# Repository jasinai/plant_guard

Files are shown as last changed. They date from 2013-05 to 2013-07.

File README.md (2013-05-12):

Plant Guard
===========

This project helps you monitoring, watering and keeping care of your (indoor) plants.

What you need
-------------

  * An Arduino Uno or similar microcontroller Board (code is written in Arduino IDE, but we plan to port it to C)
  * A WiFly shield for the arduino
  * A twitter account and a wifi in range of you plant
  * An LM35 temperature sensor
  * An LM358 Op-Amp
  * 1x 220 Ohm resistor
  * 1x 10k Ohm resistor
  * 3x 100k Ohm resistors
  * A humidity sensor, built from two plug connector pins soldered to wire (spacing is important: use standard plug connector pins for this!)
  * A 12V elecronically open- and closeable valve
  * A plastic bottle with bottom cut off and some stand to safely put it upside down
  * some water tube to connect bottle, valve and plant
  * a willing (and maybe robust) plant :)

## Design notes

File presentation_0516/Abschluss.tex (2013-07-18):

\documentclass[bigger]{beamer}
\usepackage[utf8]{inputenc}
\usepackage[T1]{fontenc}
\usepackage{color}
\usepackage{graphicx}
\usepackage{eurosym}
\usepackage{parcolumns}

\DeclareGraphicsExtensions{.png,.pdf,.jpg}
\graphicspath{{./pics/}}

%Global Background must be put in preamble
\usebackgroundtemplate%
{%
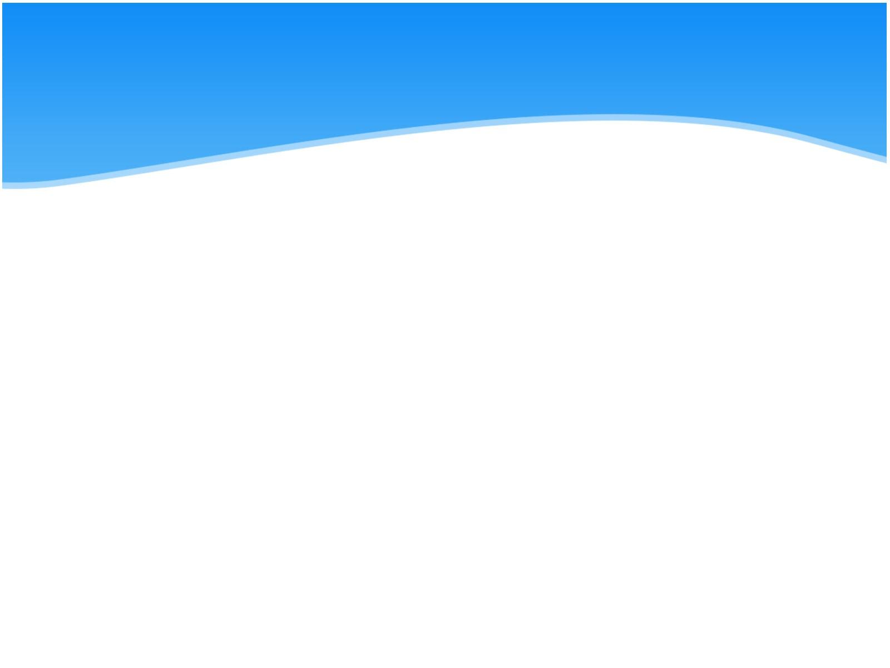
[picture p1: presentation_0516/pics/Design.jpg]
    %
}

\newcommand{\topic}[1]{{\huge{\textcolor{white}{\textbf{#1}}}}}
%\newcommand{\topic}[1]{\textbf{#1}}

\begin{document}
{
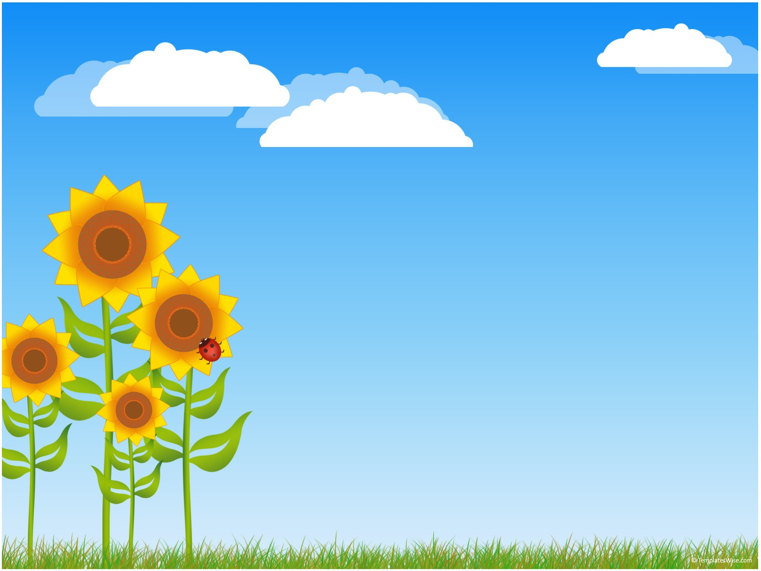
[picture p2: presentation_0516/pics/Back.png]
\usebackgroundtemplate{}%
\begin{frame}
%Title: leer, vielleicht noch unsere Namen einfügen
	\begin{figure}[H]
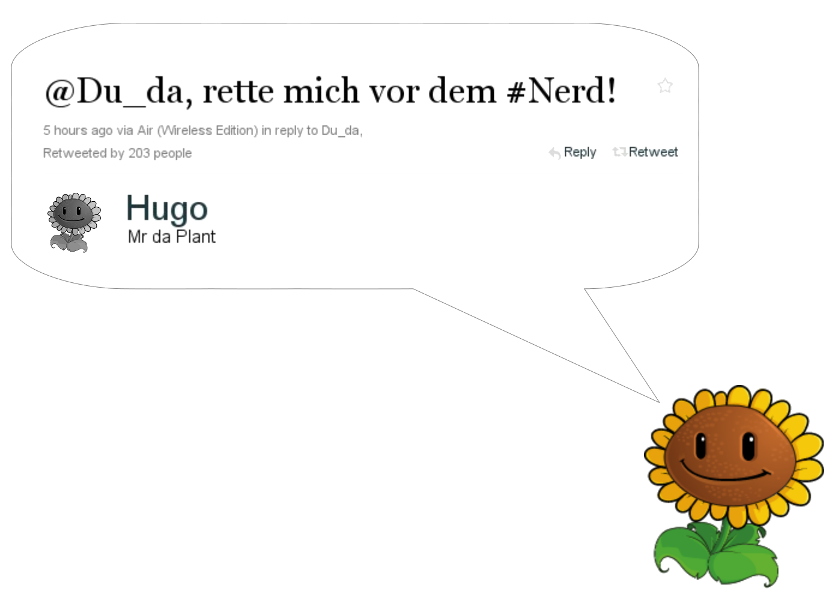
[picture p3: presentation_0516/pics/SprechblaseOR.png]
		
	\end{figure}

\end{frame}
}

\begin{frame}{\topic{Plant Guard}}
   \begin{itemize}
      \item Twitter für Kommunikation
      \item Messungen: Feuchtigkeit*, Temperatur, Wasserstand, uvm.
      \item kann Pflanzen gießen
      \item Erweiterbarkeit gegeben*
      \item Kosten sind relativ gering*
   \end{itemize}
*dazu später mehr Informationen
\end{frame}

\begin{frame}{\topic{Vergleich (andere Projekte)}}
	\begin{itemize}
		\item twittern oder nutzen spezielle Netzwerkprogramme
		\item meist keine Bewässerung (nur bei Hobbyprojekten)
		\item weniger Sensoren (meist nur Feuchtigkeit)
		\item dafür ein Projekt mit Pflanzen-DB für Konfiguration
		\item ein Bausatz/Gerät meist um {100\euro} oder nicht erhältlich
	\end{itemize}
\end{frame}

\begin{frame}{\topic{Vorteile des Plant Guard}}
	\begin{itemize}
		\item Pflanzeninfos über Twitter weltweit verfügbar
		%\item Multiuser (z.B. für die Gießvertretung)
		\item automatische Bewässerung
		\item erweiterbar (mehr Sensoren, mehr Pflanzen, ...)
		\item bei Stromausfall wird inzwischen später gegossen
	\end{itemize}
\end{frame}

\begin{frame}{\topic{Probleme}}
	\begin{itemize}
		\item Inkontinenz beim Start
		\item wenn der PlantGuard zuviel gießt, könnte der Topf überlaufen
		\item ziemlich großer Behälter, schlecht zu verstecken, leicht zu kippen, muss höher stehen als die Pflanze
		\item Abdichtung des Wasserbehälters
		\item viele und lange Kabel
		\item hohe Kosten bei verteilt stehenden Pflanzen (pro Pflanze ein PlantGuard)
	\end{itemize}
\end{frame}

\begin{frame}{\topic{Kosten}}
	\begin{itemize}
		\item Arduino+WiFly: ab 60\euro
		\item Ventil: 7,50\euro
		\item Sensoren: je nach Anzahl/Art
		\item Platine und Material: wenige \euro
	\end{itemize}
	Summe: ca. 75\euro
\end{frame}

\begin{frame}{\topic{Sensoren}}
	\begin{itemize}
		\item Temperatur
		\item Feuchtigkeit
		\item Wasserstand
	\end{itemize}
weitere Ideen folgen
\end{frame}

\begin{frame}{\topic{Temperatur}}
	\begin{itemize}
		\item benötigt einen OpAmp
		\item lange Drähte für freie Positionierung
		\item misst im Bereich der Raumtemperatur
		\item direkt auf der Platine
	\end{itemize}
\end{frame}

\begin{frame}{\topic{Temperatursensor}}
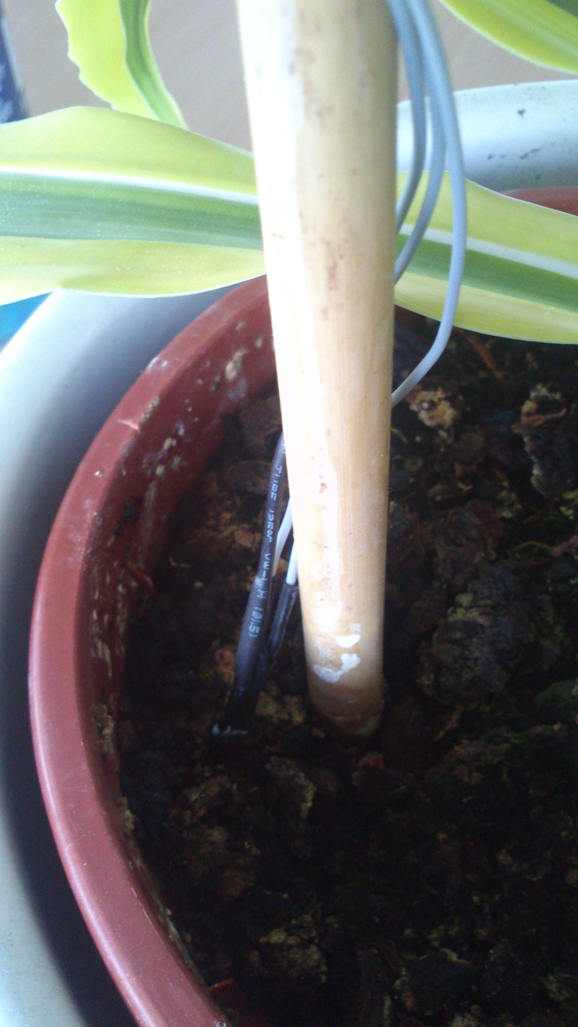
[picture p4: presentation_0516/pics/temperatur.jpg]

\end{frame}

\begin{frame}{\topic{Feuchtigkeit}}
	\begin{itemize}
		\item zwei lange Metallstäbe, die mit festem Abstand zueinander in den Boden gesteckt werden
		\item Spannungsmessung mit der Erde als Widerstand. Je niedriger der Wert, desto feuchter die Erde
		\item Nutzung von Wechselspannung (durch Umpolen von 2 Pins) schont die Pflanze
	\end{itemize}
\end{frame}

\begin{frame}{\topic{Feuchtigkeitssensor}}
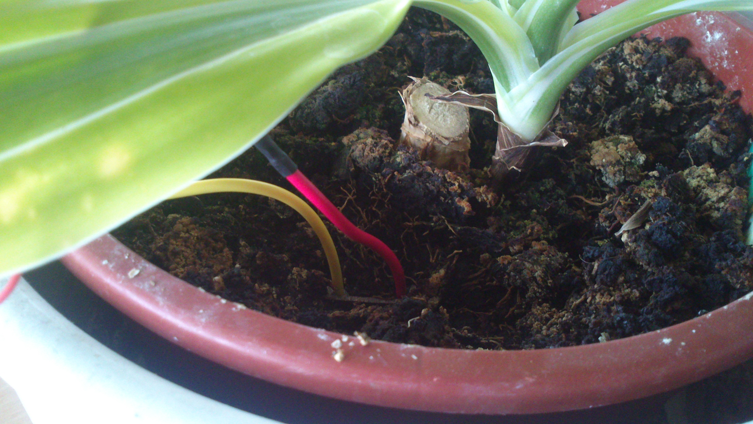
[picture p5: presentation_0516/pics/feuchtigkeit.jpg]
\begin{center}\end{center}
\end{frame}

\begin{frame}{\topic{Wasserstand}}
	\begin{itemize}
		\item zwei sehr lange Drähte mit festem Abstand
		\item am Arduino werden 4,5 bis 4,9 Volt gemessen
		\item ca. 82stufige Messungen
		\item bedingt wichtig für Nachrichten
		\item sehr wichtig für Pumpen (nur im Wasser betreiben!)
	\end{itemize}
\end{frame}

\begin{frame}{\topic{Wasserstandssensor}}
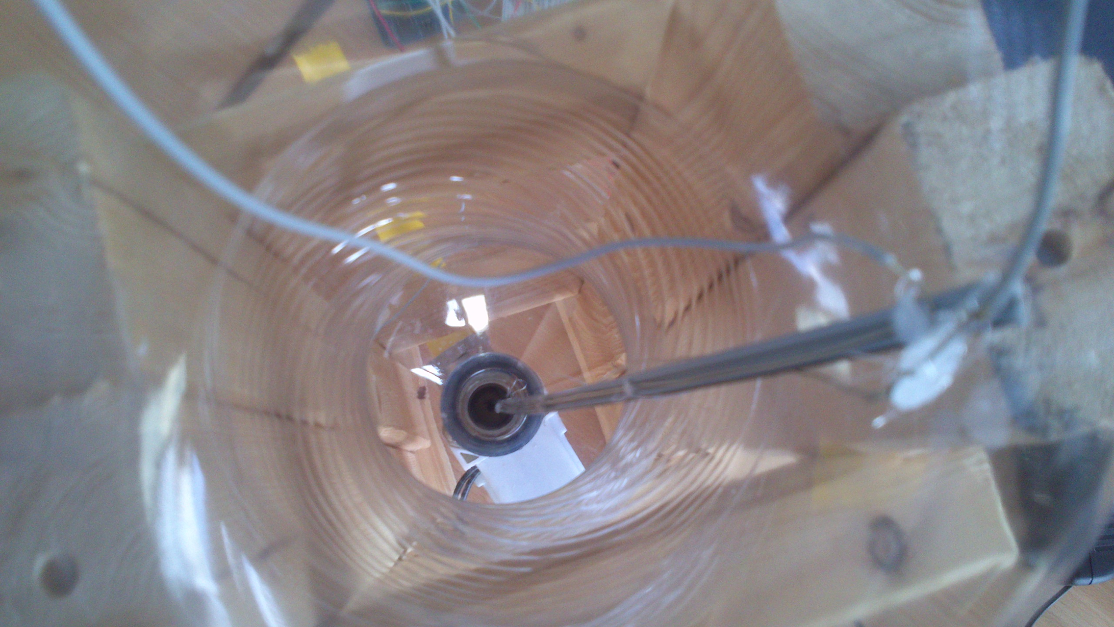
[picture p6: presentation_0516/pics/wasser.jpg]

\end{frame}

\begin{frame}{\topic{Aktuatoren/Ventil}}
	\begin{itemize}
		\item leise
		\item nutzt Schwerkraft
		\item z.Z. auf Flaschen-Tank begrenzt, generell ist der Tank ersetzbar
		\item man muss das Ventil richtig ausrichten (um nicht den Bereich um die Pflanze zu gießen)
	\end{itemize}
\end{frame}

\begin{frame}
%Bild von aktueller Platine
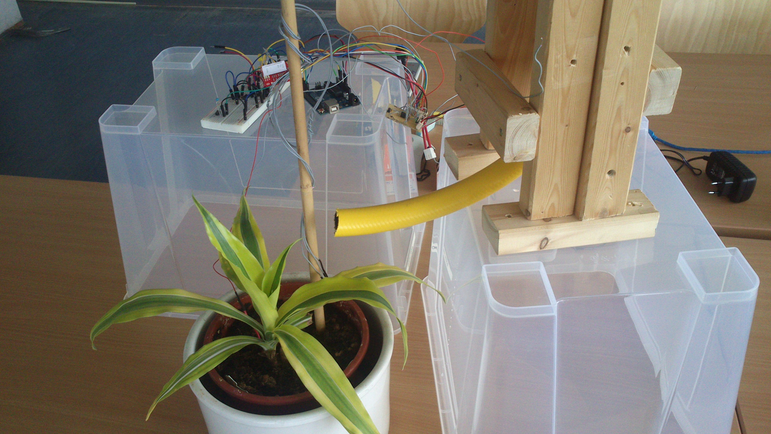
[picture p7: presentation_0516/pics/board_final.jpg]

\end{frame}

\begin{frame}
%Bild von aktueller Platine
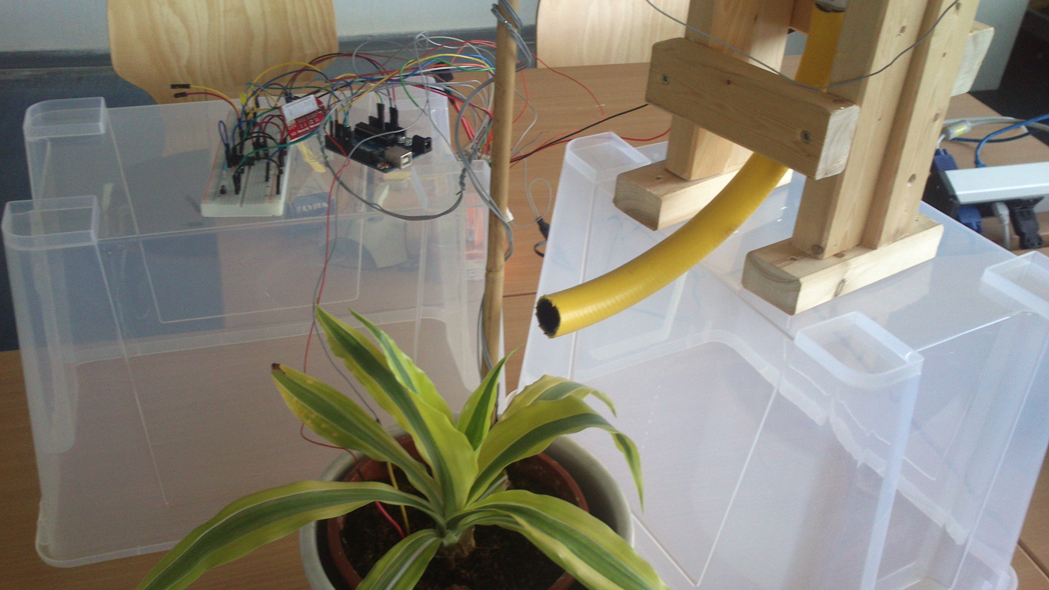
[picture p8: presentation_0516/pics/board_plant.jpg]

\end{frame}

\begin{frame}
%Bild von aktueller Platine
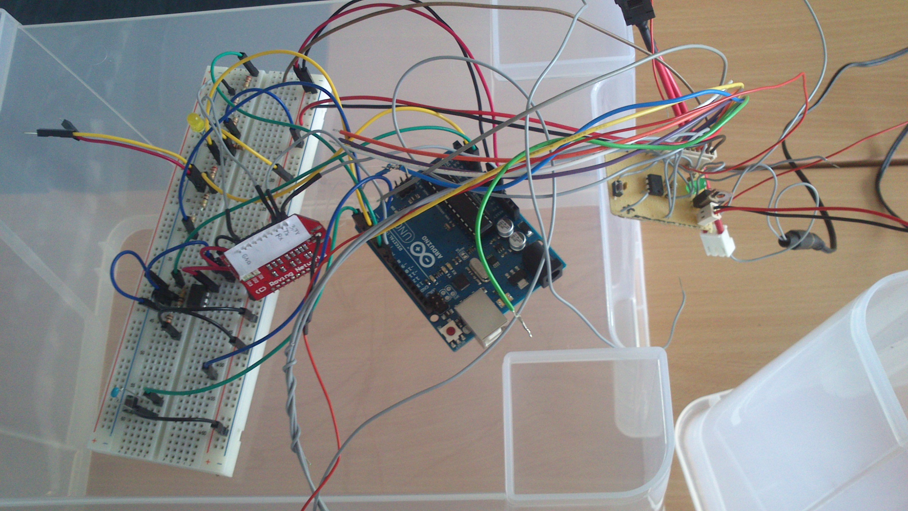
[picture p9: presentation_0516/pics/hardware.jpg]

\end{frame}

\begin{frame}{\topic{Bewässerung}}
% %früher / heute vergleich
%     \begin{columns}
%       \column[c]{.50\linewidth}
%         \begin{enumerate}
% 			\item verbreiterte Stellfläche
% 			\item Messkabel
% 			\item Ventilansteuerung
% 			\item Verbindung Vorrat $\rightarrow$ Ventil
%         \end{enumerate}
%       \column[c]{.50\linewidth}
%         \includegraphics[width=150px]{System.jpg}
%     \end{columns}
\url{http://www.youtube.com/watch?feature=player_embedded&v=Uci__lRXZsU}
\end{frame} 

\begin{frame}{\topic{Softwareübersicht}}
	\begin{itemize}
		\item 20kb groß (viel für Twitter)
		\item Regelschleife (wenn zu trocken, gieße)
		\item Zeitsteuerung mit "Gieße alle X Minuten" möglich
      \item Wichtige Parameter (z.B. Temperatur- und Feuchteschwellwerte) sind in eine Konfigurationsdatei ausgelagert
		\item liegt unter \url{http://github.com/jasinai/plant\_guard}
	\end{itemize}
\end{frame}

% \begin{frame}{\topic{Bewässerung}}
% %früher / heute vergleich
%        \includegraphics[width=350px]{Anschluss.jpg}
% \end{frame}

\begin{frame}{\topic{Tweets}}
	\begin{itemize}
      \item "Mir ist kalt! Stell mich an einen wärmeren Ort. Aktuelle Temperatur: X"
      \item "Puh, ist das warm! Ein bisschen Schatten wäre nicht schlecht. Aktuelle Temperatur: 33"
      \item "Mir ist warm. Es ist sind 30 C. Stell mich woanders hin."
      \item "Mensch, gib mir Wasser!"
	\end{itemize}
\end{frame}

\begin{frame}{\topic{mögliche Upgrades}}
	\begin{itemize}
		\item Pumpe statt Ventil (+{5\euro}, mehr Strom nötig, etwas lauter)
		\item mehr Pflanzen pro PlantGuard überwachen
		\item mehr Sensoren
		\item weg vom Arduino/WiFly
		\item Datenbank für Gießparameter
		\item diverse Hardwareverbesserungen
	\end{itemize}
\end{frame}

\begin{frame}{\topic{Pumpe statt Ventil}}
	\begin{itemize}
		\item Ventilansteuerung kompatibel mit einigen Pumpen
		\item Zeiten müssten angepasst werden
		\item Füllstand wäre noch wichtiger
		\item Behälter wäre beliebig, leichter zu verstecken
		\item kein Leck abzudichten, dafür eventuell mehr Schlauch zu verlegen
	\end{itemize}
\end{frame}

\begin{frame}{\topic{mehrere Pflanzen pro PlantGuard}}
	\begin{itemize}
		\item drückt die Kosten
		\item spart Strom (gegenüber einem Arduino pro Pflanze)
		\item mehr Anschlüsse nötig
    	\item Pflanzen sollten dicht beieinander stehen und möglichst selten bewegt werden
		\item DeMux: lange Kabel
		\item Funkchip: Protokoll ausarbeiten
	\end{itemize}
\end{frame}

\begin{frame}{\topic{weitere/andere Sensoren}}
	\begin{itemize}
		\item mehrere Feuchtigkeitssensoren
		\item längere Feuchtigkeitssensoren
		\item andere Füllstandssensorik
		\item mehrere Temperatursensoren
      	\item +Helligkeitssensor
		\item +Farbsensor, Kunstlicht/Sonne
		\item +Barometer
		\item +Kippsensor (für Notfälle)
	\end{itemize}
\end{frame}

% \begin{frame}{\topic{drahtlose Verbindung}}
% 	\begin{itemize}
% 		\item man spart sich eine (De)Mux-Platine für mehrere Messstationen
% 		\item man kann durch Anpassungen am Protokoll mehr Pflanzen versorgen
% 		\item muss gesichert werden (Übertragungsfehler, ...)
% 		\item keine Kabel quer durch den Raum/die Etage nötig
% 	\end{itemize}
% \end{frame}

% \begin{frame}{\topic{ohne Arduino}}
% 	\begin{itemize}
% 		\item NetIO mit Ethersex + SD-Karte = Webserver
% 		\item geringere Kosten, ca. 25\euro
% 		\item lange erprobt, sehr ausfallfrei
% 		\item sicher, da kein WLan benötigt wird
% 		\item kompatibel mit einem Sender-Chip
% 	\end{itemize}
% \end{frame}

\begin{frame}{\topic{Hardwareverbesserungen}}
	\begin{itemize}
		\item Hülle/Gehäuse
		\item professionelle Platine, eigenes Layout
		%\item Vorgeben zweier (De)mux-Schaltung (Norm für die Software)
	\end{itemize}
\end{frame}

\begin{frame}{\topic{Datenbank mit Pflanzendaten}}
	\begin{itemize}
		\item man müsste den PlantGuard nicht anlernen
		\item dafür aber eine Datenbank mit Informationen füllen und pflegen
		\item Datenbank liefert eine passende config.h
		\item Upload über die Arduino-IDE bzw. avrdude
		\item Nachteil: User könnte die falsche Pflanze wählen oder in der Größe irren
	\end{itemize}
\end{frame}

\usebackgroundtemplate{}%
\begin{frame}{}
	\begin{figure}[H]
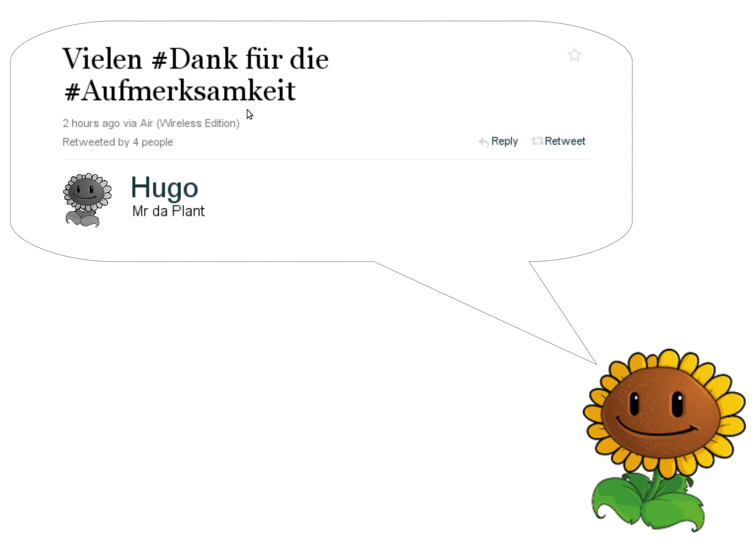
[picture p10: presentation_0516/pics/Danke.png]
		
	\end{figure}
\end{frame}

\end{document}

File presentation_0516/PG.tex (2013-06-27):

\documentclass[bigger]{beamer}
\usepackage[utf8]{inputenc}
\usepackage[T1]{fontenc}
\usepackage{color}
\usepackage{graphicx}
\usepackage{eurosym}
\usepackage{parcolumns}

\DeclareGraphicsExtensions{.png,.pdf,.jpg}
\graphicspath{{./pics/}}

%Global Background must be put in preamble
\usebackgroundtemplate%
{%
    %
}

\newcommand{\topic}[1]{{\huge{\textcolor{white}{\textbf{#1}}}}}
%\newcommand{\topic}[1]{\textbf{#1}}

\begin{document}
{
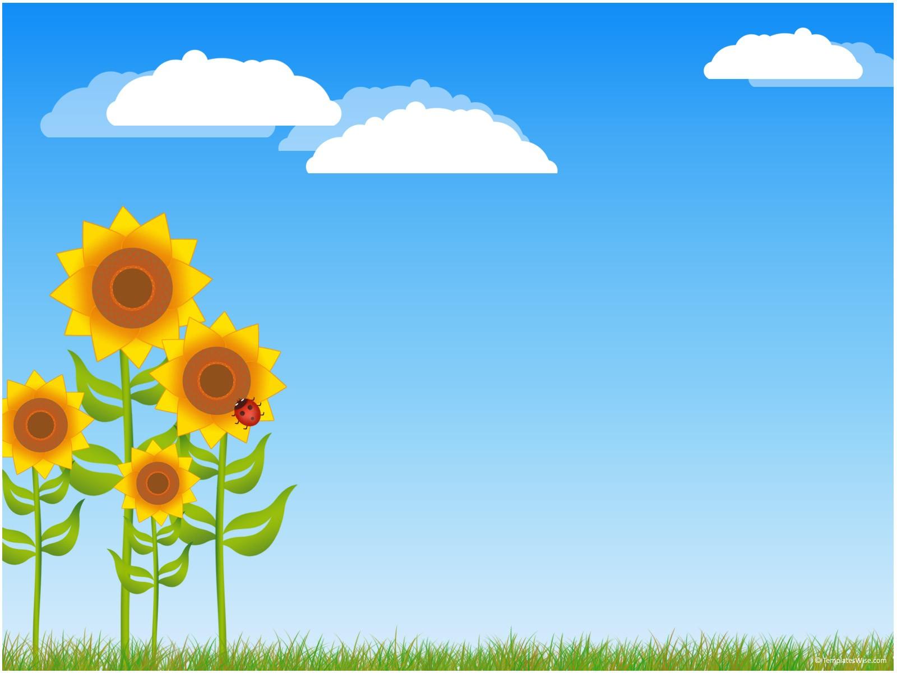
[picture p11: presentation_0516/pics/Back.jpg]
\usebackgroundtemplate{}%
\begin{frame}
%Title: leer, vielleicht noch unsere Namen einfügen
\begin{figure}[H]

\end{figure}

\end{frame}
}

\begin{frame}{\topic{Übersicht}}
   \begin{itemize}
      \item Auswahl existierender ähnlicher Projekte
      \item Vorstellung Plant Guard
      \item Zielgruppe
      \item Arbeitsstand
      \item Weitere Schritte
   \end{itemize}
\end{frame}

\begin{frame}{\topic{E-Plant}}
	\begin{itemize}
      \item Kommerzielles Projekt, Zielt auf Landwirtschaft
		\item Wird an die Pflanze angeklemmt
		\item Misst ähnlich wie ein EKG
		\item Umwelteinflüsse erkennen
		\item Wird noch nicht produziert
		\item \url{http://www.land-der-ideen.de/365-orte/preistraeger/e-plant-pflanzen-monitoring-sensor}
	\end{itemize}
\end{frame}

\begin{frame}{\topic{Botanicalls}}
	\begin{itemize}
      \item künstlerisch-wissenschaftlicher Hintergrund
		\item Twittert und/oder ruft an
		\item Nur Feuchtigkeit
		\item Bausatz kostet 100\$
		\item \url{http://www.botanicalls.com/}
	\end{itemize}
\end{frame}

\begin{frame}{\topic{Tomato Irrigation Project}}
	\begin{itemize}
      \item Hobby-Projekt
		\item Twittert
		\item Feuchtigkeitssensor
		\item automatische Bewässerung mit Pumpe
		\item nicht mehr aktiv
		\item \url{http://picasaweb.google.com/joouni/WateringSystem}
		\item \url{https://twitter.com/tomaatit}
	\end{itemize}
\end{frame}

\begin{frame}{\topic{Giess-o-mat}}
	\begin{columns}[T]
		\begin{column}{.5\textwidth}
			\begin{itemize}
            \item Hobby-Projekt
				\item automatisiertes Gießen
				\item Verwaltung der Pflanzen über Terminal
				\item Feuchtigkeitssensor
				\item \url{http://www.mikrocontroller.net/articles/Giess-o-mat}
			\end{itemize}
		\end{column}
		\begin{column}{.5\textwidth}
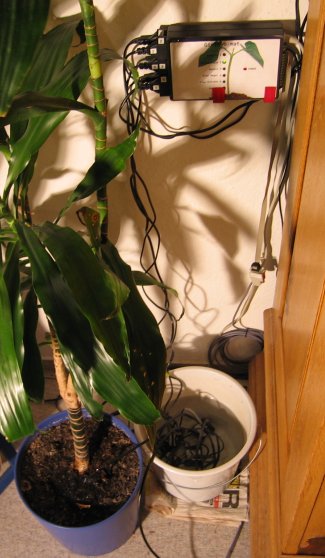
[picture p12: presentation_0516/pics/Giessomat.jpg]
			
		\end{column}
	\end{columns}
\end{frame}

\begin{frame}{\topic{GardenBot}}
	\begin{itemize}
      \item Hobby-Projekt
		\item Temperatur- und Feuchtigkeitsmessung
		\item automatisiertes Gießen
		\item Auch für den Garten gedacht
		\item (erstmal) nicht mehr aktiv
		\item \url{http://gardenbot.org/}
	\end{itemize}
\end{frame}

\begin{frame}{\topic{Koubachi}}
	\begin{itemize}
      \item kommerzielles Projekt eines schweizer Start-Ups
		\item Temperatur-, Feuchtigkeits- und Lichtsensor (nur mit Gerät)
		\item Wasser-, Düng-, Besprühplan auch ohne Gerät
		\item Gerät auch für mehrere Pflanzen, indoor und outdoor
		\item Config für Pflanzentypen im Internet
		\item Nur mit Iphone App oder Facebook-Account
		\item 90-200 Euro
		\item \url{http://www.koubachi.com/}
	\end{itemize}
\end{frame}

\begin{frame}{\topic{Parrot Flower Power}}
	\begin{itemize}
      \item kommerzielles Projekt
		\item Temperatur-, Feuchtigkeits- und Lichtsensor
		\item Düngerstandmessung
		\item Bluetooth + Smartphone
		\item Kommt irgendwann 2013 raus
		\item\url{http://www.parrot.com/flower-power/}
	\end{itemize}
\end{frame}

\begin{frame}{\topic{Patente}}
   Weiterhin existieren diverse Patente in dem Bereich, u.a. für
	\begin{itemize}
		\item selbstbewässernde Blumentöpfe
		\item Bewässerungssysteme für Bäume
      \item komplexere Systeme für die Landwirtschaft
      \item siehe auch \url{http://scholar.google.de/scholar?as_vis=1&q=plant+irrigation}
	\end{itemize}
\end{frame}

\begin{frame}{\topic{The "planned" guard}}
	\begin{itemize}
		\item Feuchtigkeitssensor
		\item Temperatursensor
		\item automatische Bewässerung
		\item Füllstandssensor
		\item Lichtsensor?
		\item einfache Möglichkeit zur Konfiguration
		\item ... und natürlich Tweets!
	\end{itemize}
\end{frame}

\begin{frame}{\topic{Abnehmer/Interessierte}}
	\begin{itemize}
		\item Neulinge, damit ihre erste Zimmerpflanze nicht ihre letzte wird
		\item Personen, die oft unterwegs sind und nicht jeden Tag zum gießen nach Hause kommen (können)
		\item Leute mit dem “braunen Daumen”, die trotzdem auf ein bisschen Grün nicht verzichten wollen
		\item Statistikhungrige (Wasserverbrauch, Lebenszeit, ...)
		\item Allen, die es einfach cool finden, wenn ihre Pflanze sich selber gießt
	\end{itemize}
\end{frame}

\begin{frame}{\topic{Bisherige Arbeiten}}
	\begin{itemize}
		\item Feuchtigkeitssensor für den Boden
		\item Temperatursensor
		\item Bewässerungsautomatisierung
		\item Grundgerüst der Software (https://github.com/jasinai/plant\_guard)
	\end{itemize}
\end{frame}
\begin{frame}
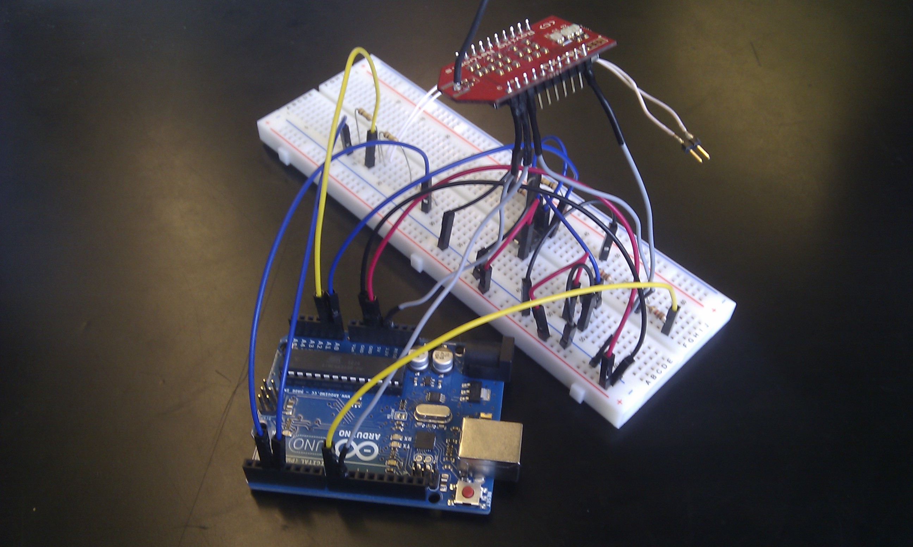
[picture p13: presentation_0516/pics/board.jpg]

\end{frame}
\begin{frame}{\topic{Temperatursensor}}
	\begin{itemize}
		\item LM35 aus dem Starterkit
	\end{itemize}
\end{frame}

\begin{frame}{\topic{Feuchtigkeitssensor}}
		\begin{itemize}
			\item Stiftleisten oder Nägel in Gips
			\item Korrisionsschutz: Wechselstrom
		\end{itemize}
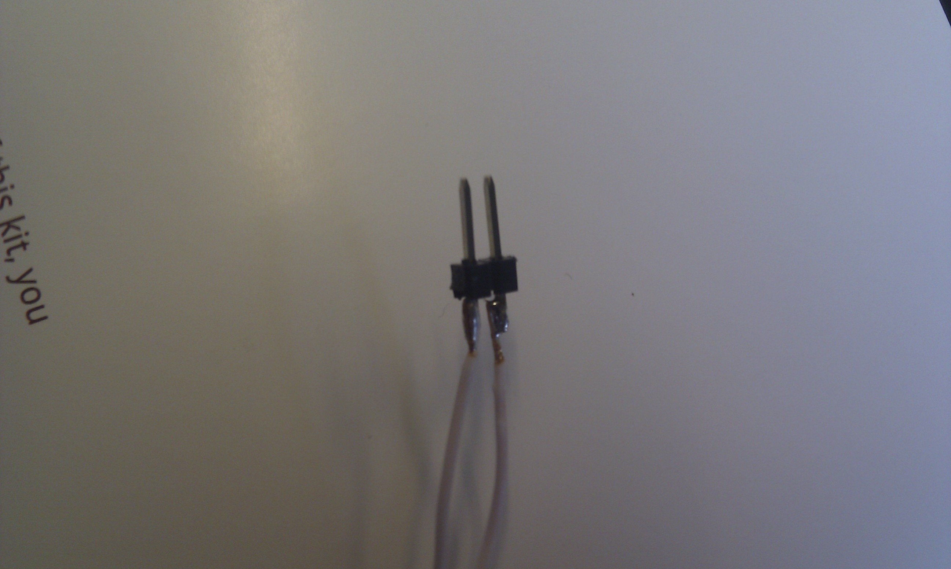
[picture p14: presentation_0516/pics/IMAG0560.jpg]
		
\end{frame}

\begin{frame}{\topic{Bewässerung}}
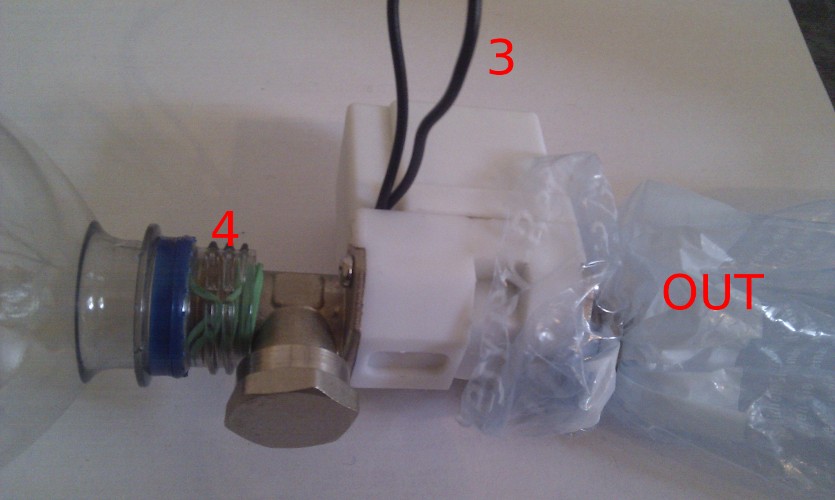
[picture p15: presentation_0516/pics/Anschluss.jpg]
       
\end{frame}

\begin{frame}{\topic{Bewässerung}}
    \begin{columns}
      \column[c]{.50\textwidth}
        \begin{enumerate}
			\item verbreiterte Stellfläche
			\item Messkabel
			\item Ventilansteuerung
			\item Verbindung Vorrat $\rightarrow$ Ventil
        \end{enumerate}
      \column[c]{.50\textwidth}
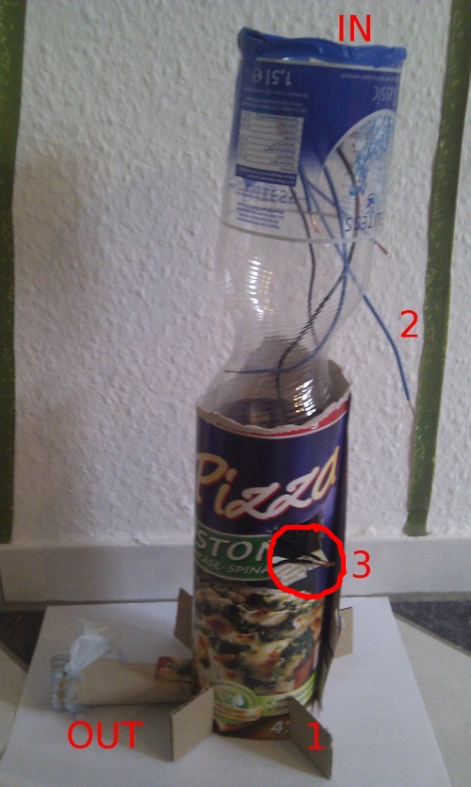
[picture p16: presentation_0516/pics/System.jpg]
        
    \end{columns}
\end{frame} 

\begin{frame}{\topic{Bewässerung}}
	\begin{itemize}
		\item Die Ventile schalten sehr leise
		\item Es wird Lageenergie genutzt
		\item mit Ventil, Pfand, Platinen, Schlauch, Dichtung, Kabeln ca. 10\euro
		\newline
		\item Pappkonstruktion ist \textbf{sehr} wasserempfindlich!
		\item Eine Konstruktion je Pflanze nötig
	\end{itemize}
\end{frame} 

\begin{frame}{\topic{Arduino}}
	\begin{itemize}
		\item mit Direktanschluss können 2 Pflanzen überwacht werden
		\item verschiedene Upgrades möglich (Anzahl++, Verteilung der Pflanzen, ...)
		\item Verpackung zum Schutz vor Wasserschäden
		\item Twittert schon
		\newline
		\item Jetzt noch messen, verarbeiten und ausgeben in einem Programm zusammenbringen
	\end{itemize}
\end{frame}

\begin{frame}{\topic{Tweets}}
	\begin{itemize}
		\item "Ich sitze schon x Tage im Dunkeln! Hat da wer die Rollos vergessen?"
		\item "Einen wunderschönen Morgen…" / "Gute Nacht!" (Uhr/Lichtsensor)
		\item "Mir ist langweilig... komm doch mal vorbei und erzähl mir was!” (Zufallsereignis)
		\item "Wasserstand niedrig: Raum x: Pflanzen-ID, Raum y: Hugo, Otto"
		\item "Die Pflanzen Hugo, Otto und Karla wurden erfolgreich gewässert!"
	\end{itemize}
\end{frame}

\begin{frame}{\topic{Vorteile}}
	\begin{itemize}
		\item Arbeitsteilung wird sehr einfach (nicht zu oft/wenig gegossen)
		\item Urlaubsvertretung braucht nur Zugriff auf Twitterdaten
		\item Gießen auf Vorrat möglich
		\item Im Gegensatz zur Konkurrenz könnten wir unser Projekt frei erweitern
		\item ... und kriegen die Daten "weltweit"!
	\end{itemize}
\end{frame}

\begin{frame}{\topic{Nachteile}}
	\begin{itemize}
		\item Stromausfall $\Rightarrow$ es wird nicht gegossen!
		\item Behälter könnte umkippen oder die Dichtung versagen
		\item Pflanzenbesitzer könnte seltener nach Schädlingen usw suchen, da "alles" automatisch funktioniert
		\item (der Behälter muss mindestens auf Höhe der Pflanze sein)
	\end{itemize}
\end{frame}

\begin{frame}{\topic{Weiteres Vorhaben}}
	\begin{itemize}
		\item Basis-Version lauffähig machen
		\item Konfiguration ermöglichen (z.B. Webinterface)
		\item Gießsystem abdichten und klonen
		\item ein Opfer für die Beta finden
	\end{itemize}
	\begin{flushright}
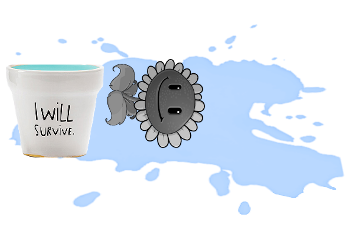
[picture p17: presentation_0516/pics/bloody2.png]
		
	\end{flushright}

\end{frame}

\begin{frame}{\topic{mögliche, nicht eingeplante Ideen}}
	\begin{itemize}
		\item mehr Sensoren (z.B. Fenster offen, Barometer, ...)
		\item mehr Pflanzen (mehr Anschlüsse durch Multiplexing / Bus / Wireless-Verbindung)
		\item "freie" Erweiterung durch User
	\end{itemize}
\end{frame}

{
\usebackgroundtemplate{}%
\begin{frame}{}
	\begin{figure}[H]
		
	\end{figure}
\end{frame}
}

\end{document}

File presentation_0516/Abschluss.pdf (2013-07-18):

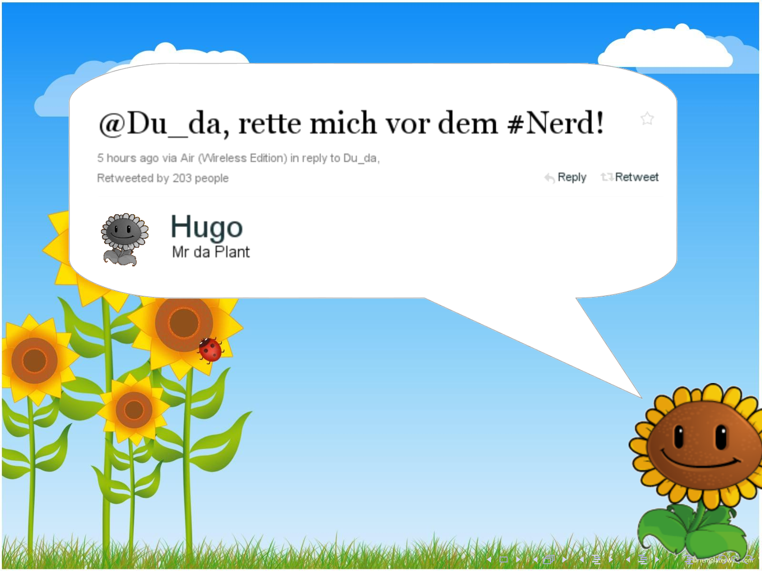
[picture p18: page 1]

# Plant Guard

I Twitter für Kommunikation
I Messungen: Feuchtigkeit*, Temperatur, Wasserstand, uvm.
I kann Pflanzen gießen
I Erweiterbarkeit gegeben*
I Kosten sind relativ gering*

*dazu später mehr Informationen

# Vergleich (andere Projekte)

I twittern oder nutzen spezielle Netzwerkprogramme I meist keine Bewässerung (nur bei Hobbyprojekten)
I weniger Sensoren (meist nur Feuchtigkeit)
I dafür ein Projekt mit Pflanzen-DB für Konfiguration I ein Bausatz/Gerät meist um 100e oder nicht erhältlich

# Vorteile

I Pflanzeninfos über Twitter weltweit verfügbar
I automatische Bewässerung
I erweiterbar (mehr Sensoren, mehr Pflanzen, ...) I bei Stromausfall wird inzwischen später gegossen

# Probleme

I Inkontinenz beim Start, da der Arduino beim Start einige Leitungen auf 1 zieht
I wenn der PlantGuard zuviel gießt, könnte der Topf überlaufen
I ziemlich großer Behälter, schlecht zu verstecken, leicht zu kippen
I Flasche nur mit Silikon 100% dicht
I viele Kabel, lange Kabel
I hohe Kosten bei verteilt stehenden Pflanzen (pro Pflante ein PlantGuard)
I Behälter muss auch weiterhin höher als die Pflanze stehen

# Kosten

I Arduino+WiFly: 60e
I NetIO+Upgrade: 25e
I Ventil: 7,50e/ Pumpe: 13e I Sensoren: je nach Anzahl/Art I Platine und Material: wenigee

Summe: ca. 35ebis 75e+x

# Sensoren

I Temperatur
I Feuchtigkeit
I Wasserstand

weitere Ideen folgen

# Temperatur

I benötigt einen OpAmp, zweiter ist noch frei I lange Drähte für freie Positionierung
I misst im Bereich der Raumtemperatur
I direkt auf der Platine

# Feuchtigkeit

I zwei lange Metallstäbe, die mit festem Abstand zueinander in den Boden gesteckt werden
I statt Widerstand messen wir Kapazität → je niedriger der Wert, desto feuchter die Erde
I Nutzung von Wechselstrom (durch Umpolen von 2 Pins) schont die Pflanze

# Wasserstand

I zwei sehr lange Drähte mit festem Abstand I am Arduino werden 4,5 bis 4,9 Volt gemessen
I ca. 82stufige Messungen
I bedingt wichtig für Nachrichten
I sehr wichtig für Pumpen (nur im Wasser betreiben!)

# Aktuatoren/Ventil

I leise
I nutzt Schwerkraft
I z.Z. auf Flaschen-Tank begrenzt, generell ist der Tank ersetzbar
I man muss das Ventil richtig ausrichten (um nicht den Bereich um die Pflanze zu gießen)

# mögliche Upgrades

I Pumpe statt Ventil (+5e, mehr Strom nötig, etwas lauter)
I mehr Pflanzen pro PlantGuard überwachen
I mehr Sensoren
I drahtlose Verbindung
I weg vom Arduino/WiFly
I Datenbank für Gießparameter I diverse Hardwareverbesserungen

# Pumpe statt Ventil

I Ventilansteuerung kompatibel mit einigen Pumpen I Zeiten müssten angepasst werden
I Füllstand wäre noch wichtiger
I Behälter wäre beliebig, leichter zu verstecken
I kein Leck abzudichten, dafür eventuell mehr Schlauch zu verlegen

# mehr Pflanzen pro PlantGuard

I drückt die Kosten
I spart Strom (gegenüber einem Arduino pro Pflanze)
I mehr Anschlüsse nötig
I Pflanzen sollten dicht beieinander stehen und möglichst selten bewegt werden
I DeMux: lange Kabel
I Funkchip: Protokoll ausarbeiten

# weitere/andere Sensoren

I mehrere Feuchtigkeitssensoren (Erdoberfläche, Topfboden, ...)
I längere Feuchtigkeitssensoren
I andere Füllstandssensorik
I mehrere Temperatursensoren (zwischen den Blättern, nahe den Wurzeln, ...)
I +Helligkeitssensor
I +Farbsensor, um zwischen Kunstlicht und Sonne zu unterscheiden
I +Barometer
I +Kippsensor (für Notfälle)

# drahtlose Verbindung

I man spart sich eine (De)Mux-Platine für mehrere Messstationen
I man kann durch Anpassungen am Protokoll mehr Pflanzen versorgen
I muss gesichert werden (Übertragungsfehler, ...)
I keine Kabel quer durch den Raum/die Etage nötig

# ohne Arduino

I NetIO mit Ethersex + SD-Karte = Webserver I geringere Kosten
I lange erprobt, sehr ausfallfrei
I sicher, da kein WLan benötigt wird
I kompatibel mit einem Sender-Chip

# Hardwareverbesserungen

I Hülle/Gehäuse
I professionelle Platine, eigenes Layout
I Vorgeben zweier (De)mux-Schaltung (Norm für die Software)

# Datenbank mit Pflanzendaten

I man müsste den PlantGuard nicht anlernen
I dafür aber eine Datenbank mit Informationen füllen und pflegen
I Datenbank liefert eine passende config.h
I Upload über die Arduino-IDE bzw. avrdude
I Nachteil: User könnte die falsche Pflanze wählen oder in der Größe irren

# Softwareübersicht

I 20kb groß (viel für Twitter)
I Regelschleife (wenn zu trocken, gieße)
I Zeitsteuerung mit "Gieße alle X Minuten" möglich I Wichtige Parameter (z.B. Temperatur- und Feuchteschwellwerte) sind in eine Konfigurationsdatei ausgelagert
I liegt unter http://github.com/jasinai/plant_guard

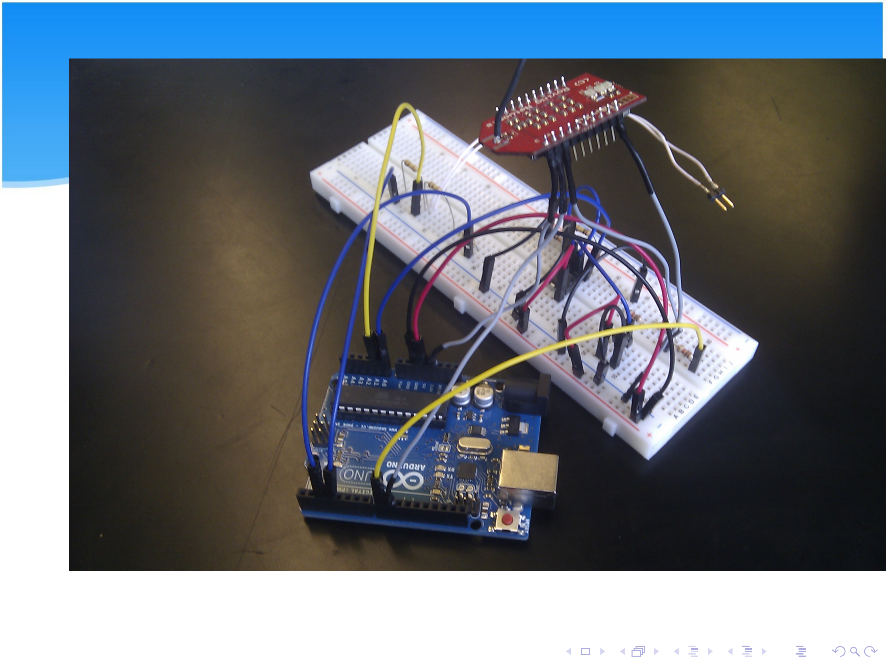
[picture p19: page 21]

# Temperatursensor

# Bewässerung

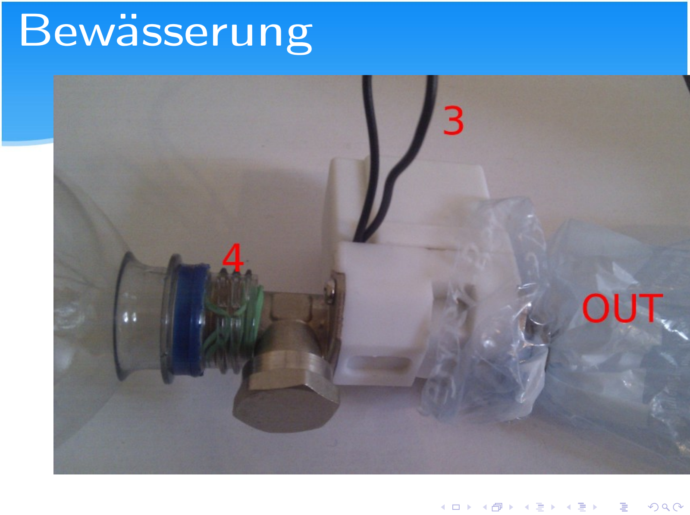
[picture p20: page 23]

# Bewässerung

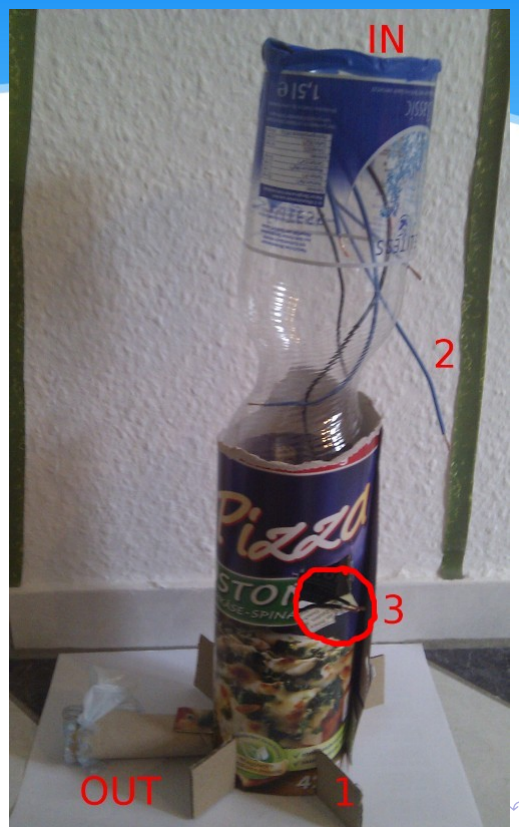
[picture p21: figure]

1. verbreiterte Stellfläche
2. Messkabel
3. Ventilansteuerung
4. Verbindung Vorrat →
Ventil

# Tweets

I "Mir ist kalt! Stell mich an einen wärmeren Ort. Aktuelle Temperatur: X"
I "Puh, ist das warm! Ein bisschen Schatten wäre nicht schlecht. Aktuelle Temperatur: 33"
I "Mir ist warm. Es ist sind 30 C. Stell mich woanders hin." I "Mensch, gib mir Wasser!"

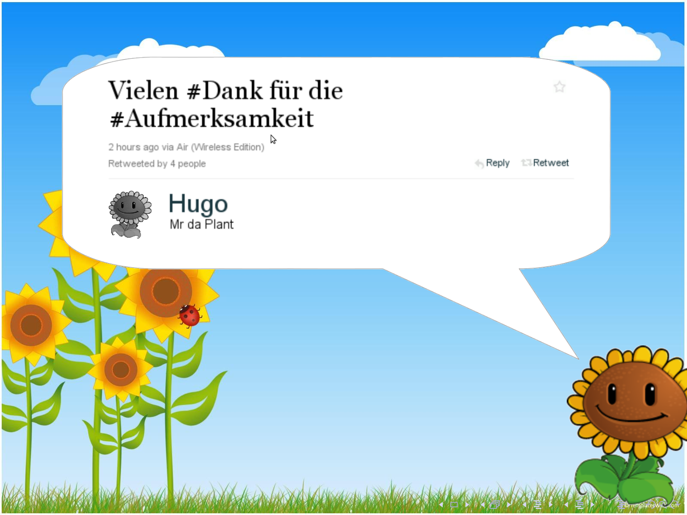
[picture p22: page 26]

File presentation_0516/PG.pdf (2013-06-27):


# Übersicht

I Auswahl existierender ähnlicher Projekte I Vorstellung Plant Guard
I Zielgruppe
I Arbeitsstand
I Weitere Schritte

# E-Plant

I Kommerzielles Projekt, Zielt auf Landwirtschaft I Wird an die Pflanze angeklemmt
I Misst ähnlich wie ein EKG
I Umwelteinflüsse erkennen
I Wird noch nicht produziert

I http://www.land-der-ideen.de/365-orte/preistraeger/
e-plant-pflanzen-monitoring-sensor (http://www.land-der-ideen.de/365-orte/preistraeger/e-plant-pflanzen-monitoring-sensor)

# Botanicalls

I künstlerisch-wissenschaftlicher Hintergrund I Twittert und/oder ruft an
I Nur Feuchtigkeit
I Bausatz kostet 100$

I http://www.botanicalls.com/

# Tomato Irrigation Project

I Hobby-Projekt
I Twittert
I Feuchtigkeitssensor
I automatische Bewässerung mit Pumpe
I nicht mehr aktiv

I http:
//picasaweb.google.com/joouni/WateringSystem I https://twitter.com/tomaatit

# Giess-o-mat

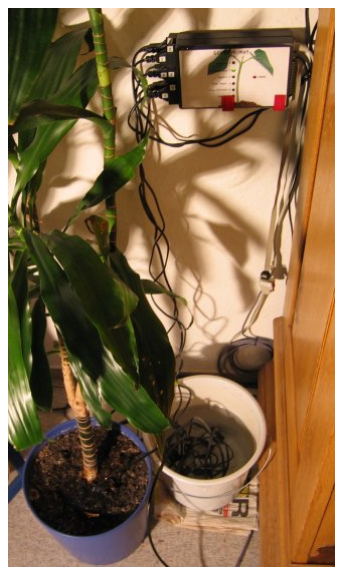
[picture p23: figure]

I Hobby-Projekt
I automatisiertes Gießen
I Verwaltung der Pflanzen
über Terminal
I Feuchtigkeitssensor

I http://www.
mikrocontroller.net/
articles/Giess-o-mat (http://www.mikrocontroller.net/articles/Giess-o-mat)

# GardenBot

I Hobby-Projekt
I Temperatur- und Feuchtigkeitsmessung I automatisiertes Gießen
I Auch für den Garten gedacht
I (erstmal) nicht mehr aktiv

I http://gardenbot.org/

# Koubachi

I kommerzielles Projekt eines schweizer Start-Ups
I Temperatur-, Feuchtigkeits- und Lichtsensor (nur mit Gerät)
I Wasser-, Düng-, Besprühplan auch ohne Gerät
I Gerät auch für mehrere Pflanzen, indoor und outdoor I Config für Pflanzentypen im Internet
I Nur mit Iphone App oder Facebook-Account
I 90-200 Euro

I http://www.koubachi.com/

# Parrot Flower Power

I kommerzielles Projekt
I Temperatur-, Feuchtigkeits- und Lichtsensor I Düngerstandmessung
I Bluetooth + Smartphone
I Kommt irgendwann 2013 raus

I http://www.parrot.com/flower-power/

# Patente

Weiterhin existieren diverse Patente in dem Bereich, u.a. für I selbstbewässernde Blumentöpfe
I Bewässerungssysteme für Bäume
I komplexere Systeme für die Landwirtschaft

I siehe auch http://scholar.google.de/scholar?as_vis=1&q=plant+irrigation (http://scholar.google.de/scholar?as_vis=1&q=plant+irrigation)

# The "planned" guard

I Feuchtigkeitssensor
I Temperatursensor
I automatische Bewässerung
I Füllstandssensor
I Lichtsensor?
I einfache Möglichkeit zur Konfiguration I ... und natürlich Tweets!

# Abnehmer/Interessierte

I Neulinge, damit ihre erste Zimmerpflanze nicht ihre letzte wird
I Personen, die oft unterwegs sind und nicht jeden Tag zum gießen nach Hause kommen (können)
I Leute mit dem “braunen Daumen”, die trotzdem auf ein bisschen Grün nicht verzichten wollen
I Statistikhungrige (Wasserverbrauch, Lebenszeit, ...)
I Allen, die es einfach cool finden, wenn ihre Pflanze sich selber gießt

# Bisherige Arbeiten

I Feuchtigkeitssensor für den Boden I Temperatursensor
I Bewässerungsautomatisierung
I Grundgerüst der Software (https://github.com/jasinai/plant_guard)


# Temperatursensor

I LM35 aus dem Starterkit

# Feuchtigkeitssensor

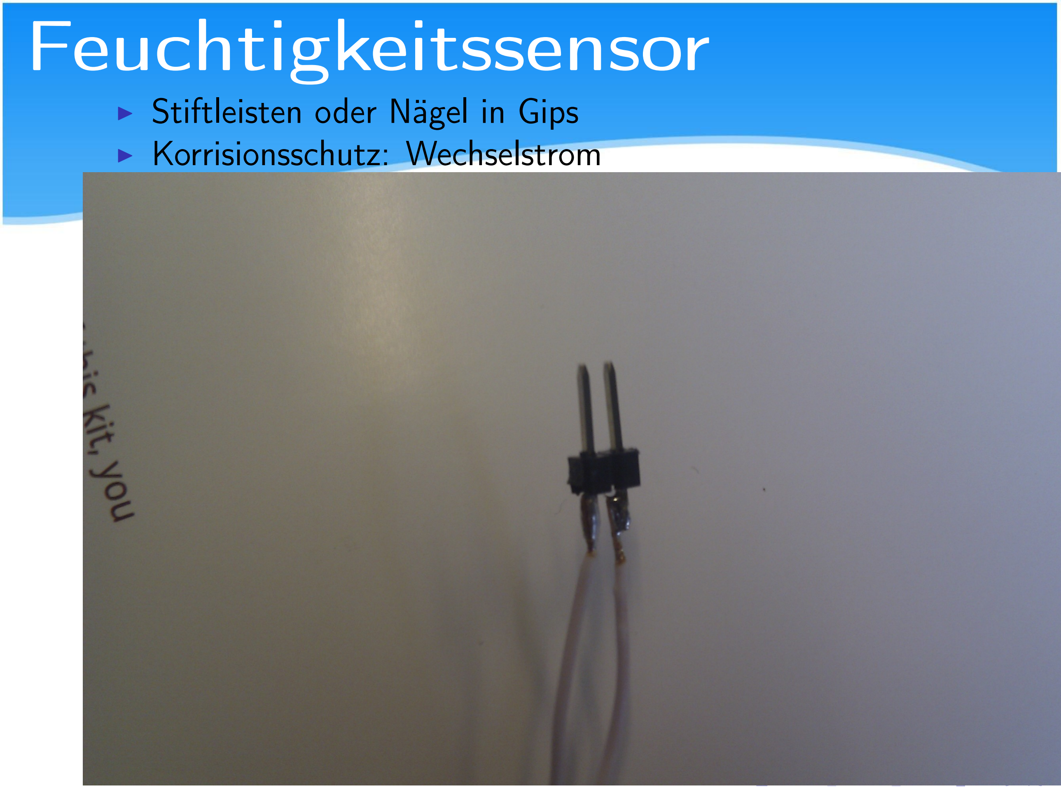
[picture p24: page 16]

I Stiftleisten oder Nägel in Gips I Korrisionsschutz: Wechselstrom

# Bewässerung


# Bewässerung


1. verbreiterte Stellfläche
2. Messkabel
3. Ventilansteuerung
4. Verbindung Vorrat →
Ventil

# Bewässerung

I Die Ventile schalten sehr leise
I Es wird Lageenergie genutzt
I mit Ventil, Pfand, Platinen, Schlauch, Dichtung, Kabeln ca. 10e

I Pappkonstruktion ist sehr wasserempfindlich!
I Eine Konstruktion je Pflanze nötig

# Arduino

I mit Direktanschluss können 2 Pflanzen überwacht werden I verschiedene Upgrades möglich (Anzahl++, Verteilung der Pflanzen, ...)
I Verpackung zum Schutz vor Wasserschäden
I Twittert schon

I Jetzt noch messen, verarbeiten und ausgeben in einem Programm zusammenbringen

# Tweets

I "Ich sitze schon x Tage im Dunkeln! Hat da wer die Rollos vergessen?"
I "Einen wunderschönen Morgen. . . " / "Gute Nacht!" (Uhr/Lichtsensor)
I "Mir ist langweilig... komm doch mal vorbei und erzähl mir was!” (Zufallsereignis)
I "Wasserstand niedrig: Raum x: Pflanzen-ID, Raum y: Hugo, Otto"
I "Die Pflanzen Hugo, Otto und Karla wurden erfolgreich gewässert!"

# Vorteile

I Arbeitsteilung wird sehr einfach (nicht zu oft/wenig gegossen)
I Urlaubsvertretung braucht nur Zugriff auf Twitterdaten I Gießen auf Vorrat möglich
I Im Gegensatz zur Konkurrenz könnten wir unser Projekt frei erweitern
I ... und kriegen die Daten "weltweit"!

# Nachteile

I Stromausfall ⇒ es wird nicht gegossen!
I Behälter könnte umkippen oder die Dichtung versagen
I Pflanzenbesitzer könnte seltener nach Schädlingen usw suchen, da "alles" automatisch funktioniert
I (der Behälter muss mindestens auf Höhe der Pflanze sein)

# Weiteres Vorhaben

I Basis-Version lauffähig machen
I Konfiguration ermöglichen (z.B. Webinterface) I Gießsystem abdichten und klonen
I ein Opfer für die Beta finden


# mögliche, nicht eingeplante Ideen

I mehr Sensoren (z.B. Fenster offen, Barometer, ...)
I mehr Pflanzen (mehr Anschlüsse durch Multiplexing / Bus / Wireless-Verbindung)
I "freie" Erweiterung durch User


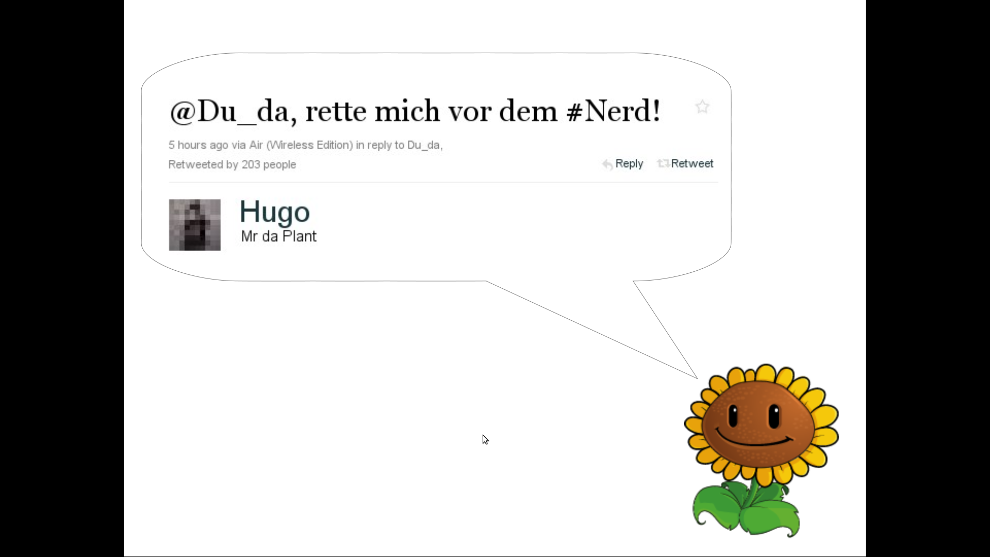
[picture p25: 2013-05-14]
presentation_0516/pics/Sprechblase.png

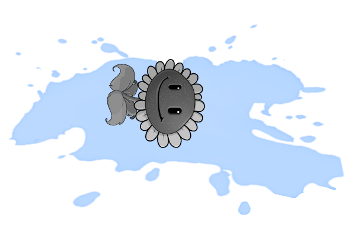
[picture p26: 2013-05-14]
presentation_0516/pics/bloody.png

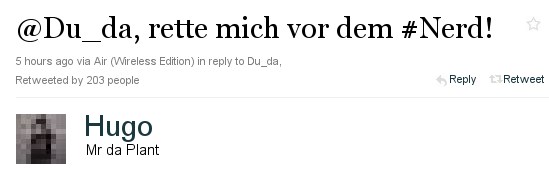
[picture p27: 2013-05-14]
presentation_0516/pics/Twitter.jpg

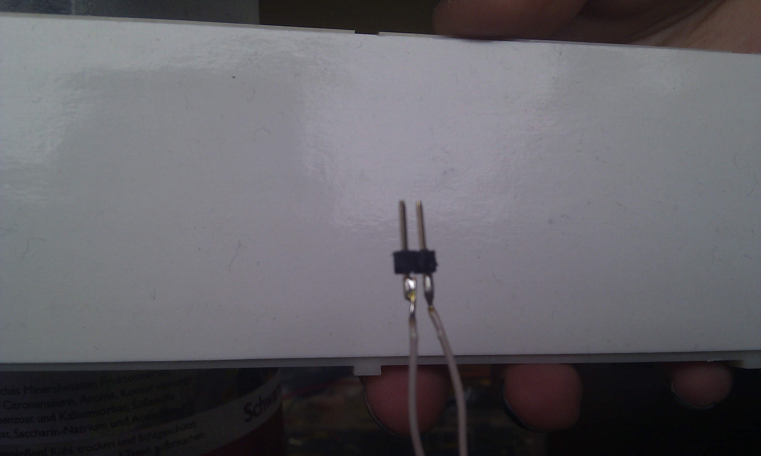
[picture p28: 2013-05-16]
presentation_0516/pics/IMAG0557.jpg

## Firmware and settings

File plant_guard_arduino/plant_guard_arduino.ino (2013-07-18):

#include <SoftwareSerial.h>
#include <SPI.h>
#include <WiFlyHQ.h>
#include <EEPROM.h>
#include <avr/sleep.h>
#include "config.h"
#include "WiFlyTwitter.h"

uint8_t button_pressed = 0;
int out = 0;
int temp_value = 0;
uint8_t temperature = 0;
uint16_t humid_result = 0;
uint16_t last_humidity = 0;
uint16_t humid_dry = DRY, humid_wet = WET;
uint8_t water = 0;
uint32_t seconds = 0, next_measurement = 0;
uint16_t eeprom_count = 0;
WiFlyTwitter twitter;
char s[160] = "";
uint8_t count = 0;

//TEMPERATURE TEXTS
const char *TOO_COLD_TEXT = "Mir ist kalt. Es ist sind %u°C. Mach mal die Heizung an!";
const char *TOO_HOT_TEXT = "Mir ist warm. Es ist sind %u°C. Stell mich woanders hin.";
//WATER/HUMIDITY TEXTS
const char *WATER_EMPTY_TEXT = "Hilfe, mein Wasservorrat ist alle.";
const char *WATER_ALMOST_EMPTY_TEXT = "Mein Wasservorrat geht zur Neige.";
const char *WATERED_TEXT = "Ah, das war erfrischend.";
const char *WATER_FROM_HUMAN_TEXT = "Mensch, gib mir Wasser!";
//RANDOM TEXTS
const char *RANDOM_TEXT_1 = "Mir ist langweilig… komm doch mal vorbei und erzähl mir was!";
const char *RANDOM_TEXT_2 = "Guck mal aus dem Fenster. Ich glaub da passiert was.";
const char *RANDOM_TEXT_3 = "Zu spät geguckt.";
const char *RANDOM_TEXT_4 = "Lebst du noch oder du gießt du schon?";

void setup() {
  // Set up timer for counting seconds
  TCCR1A = 0;
  TCCR1B = 0;
  // WGM1 <= 0100 (Clear timer when Value == OCR1A)
  TCCR1B |= (1 << WGM12);
  // CS1 <= 101 (Timer Frequency = clk_IO / 1024)
  TCCR1B |= (1 << CS12) | (1 << CS10);
  // Set max value for timer. 15625 * 1024 == 16.000.000 (clk_IO)
  OCR1A = 15625;
  // Enable Timer1 output compare A interrupt
  TIMSK1 |= (1 << OCIE1A);

  Serial.begin(115200);
  pinMode(ONBOARD_LED, OUTPUT);
  pinMode(VOLTAGE_FLIP_1, OUTPUT);
  pinMode(VOLTAGE_FLIP_2, OUTPUT);
  pinMode(HUMID_IN, INPUT);
  pinMode(WATER_VALVE, OUTPUT);
  digitalWrite(WATER_VALVE, LOW);

  // Button for accessing the data
  pinMode(BUTTON_PIN, INPUT_PULLUP);
  delay(10);
  EIMSK |= (1 << INT0);     // Enable external interrupt INT0
  EICRA |= (1 << ISC01);    // Trigger INT0 on falling edge
  EIFR = (1 << INTF0);      // Reset Interrupt flag
  sei(); // library function for interrrupt enabling

  if (ONLINE) twitter.setupWiFly();
  //if (ONLINE) twitter.post("I'm alive");

  set_sleep_mode(SLEEP_MODE_IDLE);

  // Take a measurement as soon the loop starts
  next_measurement = seconds;
}

void loop()
{
  // Toggle LED every second so that we know the program is not stuck somewhere
  digitalWrite(ONBOARD_LED, seconds & 1 ? HIGH : LOW);

  if (seconds >= next_measurement) {
    next_measurement += MEASURE_INTERVAL;
    Serial.print("Measuring... ");

    measure_humidity();
    give_water();
    was_watered();
    check_water();
    Serial.println(humid_result);

    measure_temperature();
    Serial.println(temperature);
    twitter_temperature();

    // output
    //Serial.println(voltage);
    if(DEBUG)
    {
      humidity_to_eeprom();
      humidity_to_twitter();
    }
  }

  if (button_pressed)
  {
    print_or_reset_eeprom();
  }

  // Power down the microcontroller.
  // Will wake up every second due to Timer1 compare match.
  //asm("sleep\n");
  //delay(100);
  sleep_mode();
}

void setSensorPolarity(boolean flip){
  if(flip){
    digitalWrite(VOLTAGE_FLIP_1, HIGH);
    digitalWrite(VOLTAGE_FLIP_2, LOW);
  } else {
    digitalWrite(VOLTAGE_FLIP_1, LOW);
    digitalWrite(VOLTAGE_FLIP_2, HIGH);
  }
}

// humidity sensing
void measure_humidity()
{
  uint16_t humid_value_1, humid_value_2;
  setSensorPolarity(true);
  delay(FLIP_TIMER);
  humid_value_1 = analogRead(HUMID_IN);
  delay(FLIP_TIMER);
  setSensorPolarity(false);
  delay(FLIP_TIMER);
  humid_value_2 = 1023 - analogRead(HUMID_IN);
  last_humidity = humid_result;
  humid_result = (humid_value_1 + humid_value_2) / 2;
}

void give_water()
{
  if(humid_result > DRY - DELTA_HUMID){ // THIS IS WATAAAAAAAAA!
    if(!is_water_middle())
    {
      if (ONLINE) Serial.println(twitter.post(WATER_FROM_HUMAN_TEXT));
    }
    else
    {
      digitalWrite(WATER_VALVE, HIGH);
      delay(3000);
      digitalWrite(WATER_VALVE, LOW);
    }
  }
}

void was_watered()
{
  if(last_humidity > humid_result && last_humidity - humid_result > DELTA_HUMID){ // plant was most likely watered
    humid_dry = last_humidity;
    humid_wet = humid_result;
    if (ONLINE) Serial.println(twitter.post(WATERED_TEXT));
  }
}
uint8_t water_fill_level()
{
  uint16_t water;
  water = analogRead(FILL_IN);
  water -= 1023*4.5/5.0; // 920-1023 --> 0-83
  return (uint8_t)water;
}

boolean is_water_high() {
  return (water >= 55);
}

boolean is_water_middle() {
  return (water >= 30);
}

void check_water()
{
  water = water_fill_level();
  if(!is_water_high() && is_water_middle())
  {
    if (ONLINE) Serial.println(twitter.post(WATER_ALMOST_EMPTY_TEXT));
  }
  else if(!is_water_high() && !is_water_middle())
  {
    if (ONLINE) Serial.println(twitter.post(WATER_EMPTY_TEXT));
  }
}

void measure_temperature()
{
    // temperature sensing
    uint16_t temp_value = analogRead(TEMP_IN);
    temperature =  (uint8_t) ((temp_value * 50) / 1023);
}

void twitter_temperature()
{
  if(temperature <= TOO_COLD){
    post_temperature(TOO_COLD_TEXT);
  }
  else if(temperature >= TOO_HOT){
    post_temperature(TOO_HOT_TEXT);
  }
}

void post_temperature(const char *text)
{
  char msg[141];
  snprintf(msg, 141, text, temperature);
  msg[140] = '\0';  // snprintf doesn't write \0 if string is too long.
  if (ONLINE) Serial.println(twitter.post(msg));
  if (DEBUG) Serial.println(msg);
}

void read_out_eeprom() {
  uint16_t count = eeprom_read_uint16(EEPROM_COUNTER_ADDRESS);
  Serial.print("EEPROM contains ");
  Serial.print(count);
  Serial.println(" values:");
  for (uint16_t i = 0; i < count; i++) {
    Serial.println(EEPROM.read(i));
  }
}

void eeprom_write_uint16(uint16_t address, uint16_t value) {
  EEPROM.write(address, value & 0xFF); // Low byte
  EEPROM.write(address + 1, (value >> 8) & 0xFF); // High byte
}

uint16_t eeprom_read_uint16(uint16_t address) {
  return (EEPROM.read(address)) | (EEPROM.read(address + 1) << 8);
}


ISR(INT0_vect) // BUTTON_PIN is low (trigger on low because it was set to HIGH before)
{
  button_pressed = 1;
}

// Timer1 compare match interrupt. Will be called every second.
ISR(TIMER1_COMPA_vect)
{
  seconds++;
}

void humidity_to_eeprom()
{
  // Store humidity values (scaled to 8 bit) in EEPROM
  eeprom_count = eeprom_read_uint16(EEPROM_COUNTER_ADDRESS);
  if (eeprom_count < EEPROM_COUNTER_ADDRESS)
  {
    EEPROM.write(eeprom_count, (uint8_t) (humid_result >> 2));
    eeprom_count++;
    eeprom_write_uint16(EEPROM_COUNTER_ADDRESS, eeprom_count);
  }
}

void humidity_to_twitter()
{
  sprintf(s+strlen(s), "%d ", humid_result);
  count++;
  if(count == 24)
  {
    if (ONLINE) Serial.println(twitter.post(s));
    count = 0;
    *s = '\0';
  }
}

void print_or_reset_eeprom()
{
  button_pressed = 0;
  if(DEBUG) read_out_eeprom();

  uint8_t i = 0, steps = 200;
  for (i = 0; i < steps; i++)
  {
    if (digitalRead(BUTTON_PIN) == HIGH) break; // Escape when button is released.
    delay(10);
  }
  if (i == steps && DEBUG) // The button was pressed during the whole loop.
  {
    Serial.println("Button was held for more than 2 seconds, will now erase EEPROM.");
    eeprom_write_uint16(EEPROM_COUNTER_ADDRESS, 0);
  }
}

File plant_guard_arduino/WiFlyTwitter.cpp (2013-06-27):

#include <WiFlyHQ.h>
#include "WiFlyTwitter.h"
#include "config.h"
#include <SoftwareSerial.h>
uint8_t parseStatus;
int statusCode;
WiFly wiFly;
SoftwareSerial wiFlySerial(FROM_WIFLY_PIN, TO_WIFLY_PIN); //RX PIN3, TX PIN2

    WiFlyTwitter::WiFlyTwitter(){

    }
    WiFlyTwitter::~WiFlyTwitter(){

    }
void WiFlyTwitter::setupWiFly(){
  Serial.println("Setting up WiFly...");

  //char buf[32];
  wiFlySerial.begin(9600);
  if(!wiFly.begin(&wiFlySerial, &Serial)){
    Serial.println("Failed to start wiFly"); 
  }

  wiFly.setJoin(0); // Disable auto join
  wiFly.leave();
  
  //if(!wiFly.isAssociated()){
  Serial.println("Joining network ");
  wiFly.setSSID(SSID);
  wiFly.setPassphrase(PASSPHRASE);
  wiFly.enableDHCP();
  if(wiFly.join()){
    Serial.println("Joined the network ");
  }
  else{
    Serial.println("Failed to join the network");
  }
 // }
}

bool WiFlyTwitter::checkStatus(Print *debug)
{
  if (!wiFly.isConnected()) {
    wiFly.flush();
    //wiFly.stop();
    return false;
  }
  if (!wiFly.available())
    return true;
  char c = wiFly.read();
  switch(parseStatus) {
  case 0:
    if (c == ' ') parseStatus++; break;  // skip "HTTP/1.1 "
  case 1:
    if (c >= '0' && c <= '9') {
      statusCode *= 10;
      statusCode += c - '0';
    } else {
      parseStatus++;
    }
  }
  return true;
}

int WiFlyTwitter::wait(Print *debug)
{
  while (checkStatus(debug));
  return statusCode;
}

int WiFlyTwitter::post(const char *msg){
  int status = NULL;
  if(postToTwitter(msg)){
    status = wait(NULL);
    if(status == 200){
      Serial.println("Yay");
    }
    else{
      Serial.println("Message could not be sent, error code:");
      Serial.println(status);
    }
  }
  else {
    Serial.println("Connection failed");
    status = 303;
  }
  return status;
}

bool WiFlyTwitter::postToTwitter(const char *msg){
  if(wiFly.isConnected()){
    wiFly.close();
  }
  
  if(wiFly.open(LIB_DOMAIN, 80)) {
    Serial.println("Connected");
    parseStatus = 0;
    statusCode = 0;
    wiFly.println("POST http://" LIB_DOMAIN "/update HTTP/1.0");
    wiFly.print("Content-Length: ");
    wiFly.println(strlen(msg)+strlen(TWITTER_TOKEN)+14);
    wiFly.println();
    wiFly.print("token=");
    wiFly.print(TWITTER_TOKEN);
    wiFly.print("&status=");
    wiFly.println(msg);
    return true;
  } else{
    return false;
  }
}

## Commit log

2013-04-26 Added Arduino project and fritzing schematic
    I just took the example for temperature sensing with LM35 and
    an opamp (LM358) and put some code up. Also did a quick schematic
    sketch using the fritzing software (fritzing.org).
    [schematic.fzz]
2013-04-26 basic humidity sensing
    using the low-cost sensor described in the wiki and analog in for measuring.
2013-04-26 humidity sensor with voltage flipping
    schematic update coming soon.
    [plant_guard_arduino.ino]
2013-04-26 updated schematic with humidity sensor.
    [schematic.fzz]
2013-05-16 Added pics of the board to the pdf.
2013-06-27 Added the wifly to the schematic and added the config.h the gitignore
    [schematic.fzz]
2013-06-27 little cleanup, better name for pin 13 (LED)
2013-06-27 added watering guessing mechanism
    new values in config.h for plant humidity levels and threshold value
    for watering change. saving last value in loop function and comparing
    for watering detection.
    I saw a problemn somewhere in that loop code, but I forgot -.-
    maybe it will come back later.
    [example_config.h, plant_guard_arduino.ino]
2013-07-04 added temperature threshold values to config and checked them in program
    the plant should now tweet if it's too cold or too warm. definitions of
    "cold" and "warm" can be made in config.h .
    Not sure if formatted tweets work, we will see.
2013-07-04 temperature measurement now returns uint16_t
2013-07-04 Changes the temperature messages.
2013-07-04 added code for watering
    valve must be connected to pin 7.
2013-07-04 changed mode for water button from INPUT to ONPUT_PULLUP.
    this should prevent random button triggering.
    [plant_guard_arduino.ino]
2013-07-04 temperature tweets updated
2013-07-11 Fill level inserted.
2013-07-11 Improved EEPROM management via push button Added ONLINE flag to enable/disable WiFly Button now disconnected from waternig function
2013-07-17 Cleans the code a bit up. Adds code for posting temperature tweets, water tweets.
2013-07-18 kompilieren vergessen und gleich einen fehler gefunden...
